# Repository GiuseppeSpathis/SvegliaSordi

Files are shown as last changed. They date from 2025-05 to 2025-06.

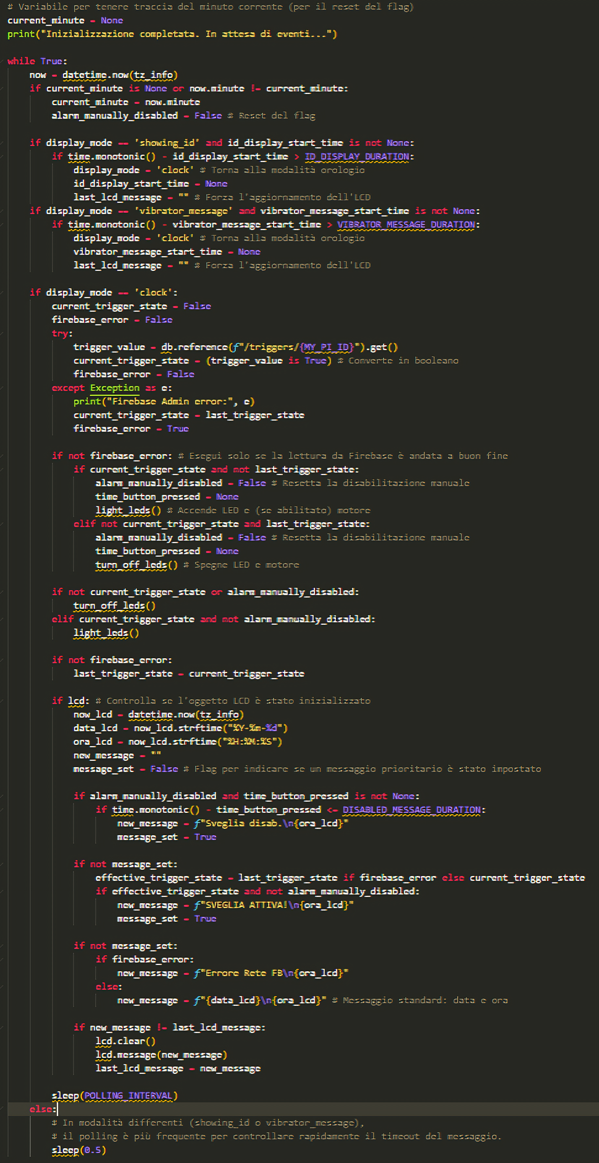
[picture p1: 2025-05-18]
utilsRelazione/codeBlocks4.PNG

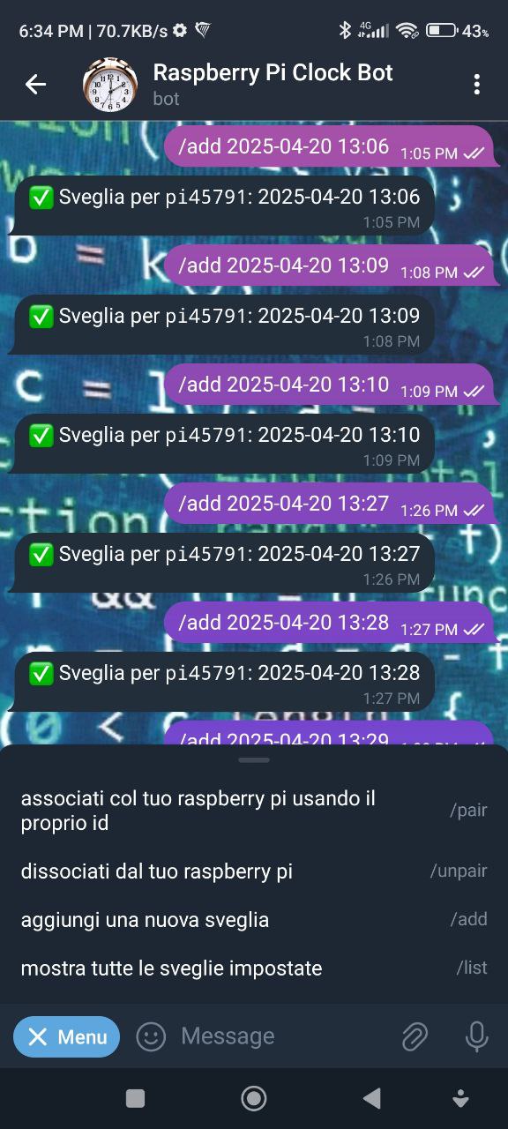
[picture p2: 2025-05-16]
utilsRelazione/botTelegram.jpg

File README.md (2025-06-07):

# SvegliaSordi
This project, titled "Sveglia per Sordi" (Alarm Clock for the Deaf), aims to create an alarm clock specifically designed for individuals who are deaf, hard of hearing, or have other auditory difficulties. Instead of traditional acoustic stimuli, the device uses visual (LED lights) and tactile (a vibrating motor, e.g., placed under a pillow) signals to wake the user.

The alarm clock can be controlled remotely via a Telegram bot ("Raspberry Pi Clock Bot"), allowing users to set, modify, or delete alarms. The system supports multiple users, with each alarm associated with a specific Raspberry Pi, making it scalable. Alarm data is stored in a Firebase Realtime Database for synchronization across devices. The Telegram bot management runs on a separate server, while a Python script on a Raspberry Pi Zero continuously monitors the database and activates the alarm signals (LEDs and vibration) at the scheduled time. The project also includes a custom 3D-printed case to house all the components, creating a compact and user-friendly device.

Key innovative aspects include the combined use of visual and tactile stimuli, remote alarm management via Telegram and a Firebase data synchronization for multi-device access

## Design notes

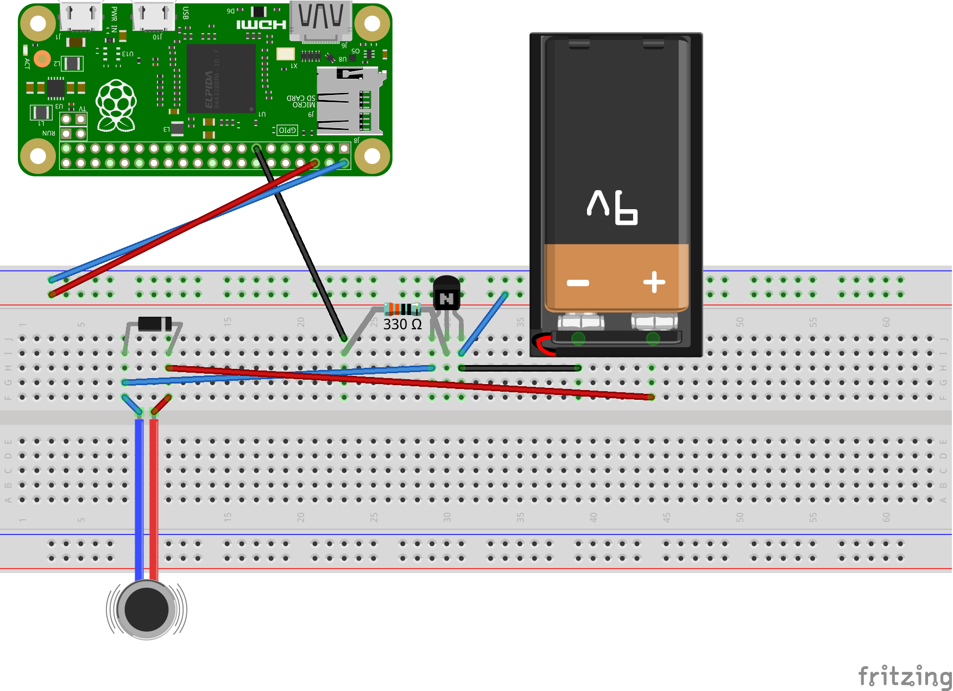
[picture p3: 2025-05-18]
utilsRelazione/vibratorMotor_fritzing.png

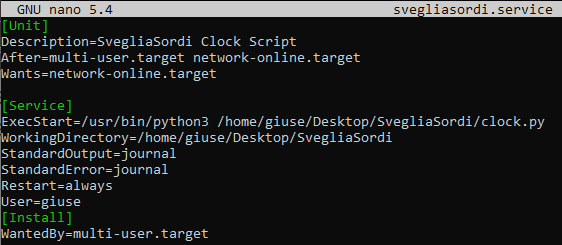
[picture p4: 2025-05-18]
utilsRelazione/ServiceBlock.PNG

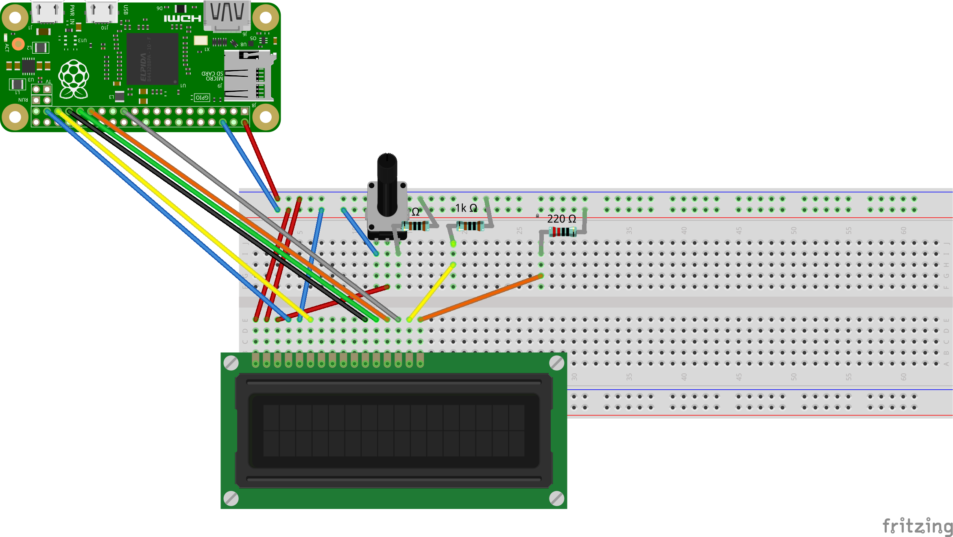
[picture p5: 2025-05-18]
utilsRelazione/schemaLcd_fritzing.png

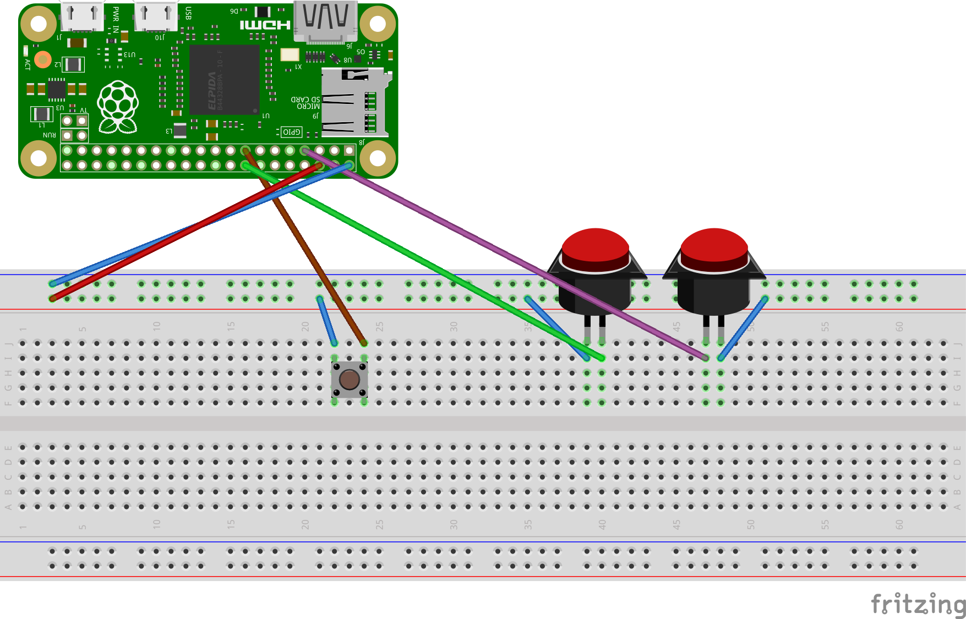
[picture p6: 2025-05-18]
utilsRelazione/buttons_fritzing.png

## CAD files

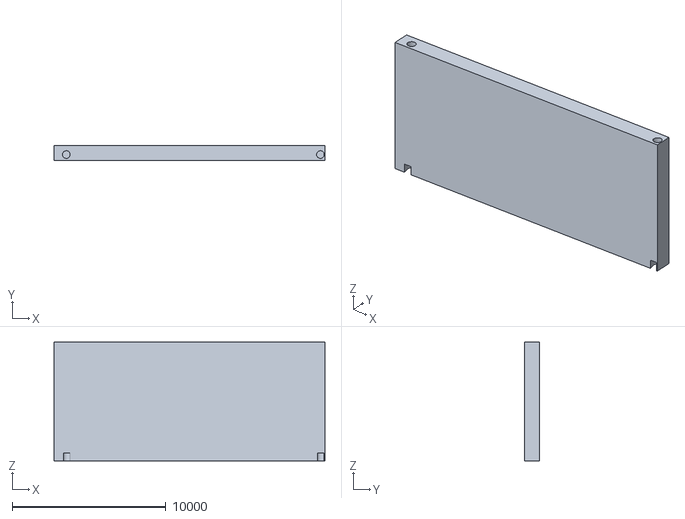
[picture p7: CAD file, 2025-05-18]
blueprint3d/parete_only_no_holes.stl
17600.0 x 1000.0 x 7700.0

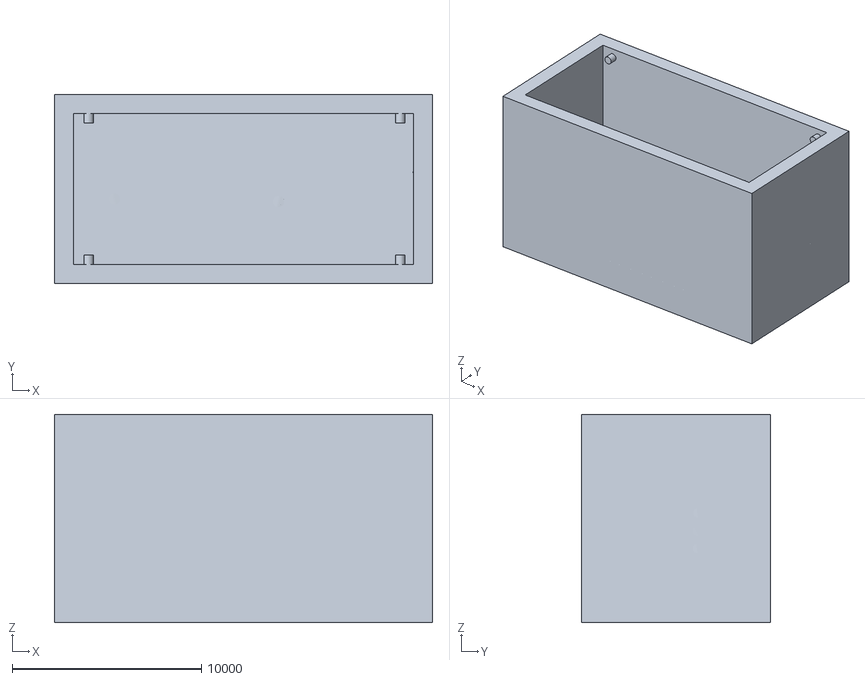
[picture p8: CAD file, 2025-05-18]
blueprint3d/case_only_no.stl
20000.0 x 10000.0 x 11016.2

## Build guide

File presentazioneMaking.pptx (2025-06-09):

## Università di Bologna Dipartimento di informatica LABORATORIO DI MAKING

Progetto “Sveglia per Sordi”
Di Giuseppe Spathis

Prof. Federico Montori
Prof. Renzo Davoli
______________________________________________________________________________________________
Anno Accademico: 2024-2025

## OBIETTIVO

L'obiettivo del mio progetto è creare una sveglia innovativa pensata per chi ha difficoltà uditive, ma anche per chi, come me, non sente le sveglie tradizionali (ad esempio, a causa dell'uso di tappi per le orecchie).
Questa sveglia non usa suoni, ma si basa su segnali visivi e tattili. Al momento del risveglio, attiverà:
- LED luminosi
- Un motorino vibrante, ideale da mettere sotto il cuscino.
Questa soluzione nasce da un'esigenza personale, ma mira a offrire un risveglio efficace, affidabile e personalizzabile a tutti coloro che cercano un'alternativa valida alle sveglie acustiche.

## ANALISI DELLA LETTERATURA

Le sveglie esistenti per persone sorde spesso usano la vibrazione o, in alcuni casi, leggere scosse elettriche. È stata esclusa l’idea di scosse, ritenendole troppo invasive per l'uso quotidiano.
Per questo, è stato scelto di focalizzarsi sulla vibrazione, ma è stata integrata con un sistema di segnalazione visiva a LED.

## FUNZIONALITÀ

- Controllo Remoto: gestione via Telegram Bot.
- Gestione Sveglie: imposta, modifica o cancella sveglie facilmente.
- Multiutenza: supporto per più utenti e scalabilità
- Database Realtime: dati sveglie salvati e sincronizzati con Firebase.
- Architettura Distribuita: bot Telegram su server dedicato.
- Script Python su Raspberry Pi Zero per attivazione sveglie.
- Design Ottimizzato: case 3D personalizzato per un dispositivo compatto e pronto all'uso.

## BOT TELEGRAM

Immagine che contiene testo, schermata, software, design Il contenuto generato dall'IA potrebbe non essere corretto.

- Bot Telegram creato con BotFather.
- Funzionalità Chiave: aggiunta nuove sveglie, modifica sveglie esistenti e sistema di pairing

## DATABASE FIREBASE

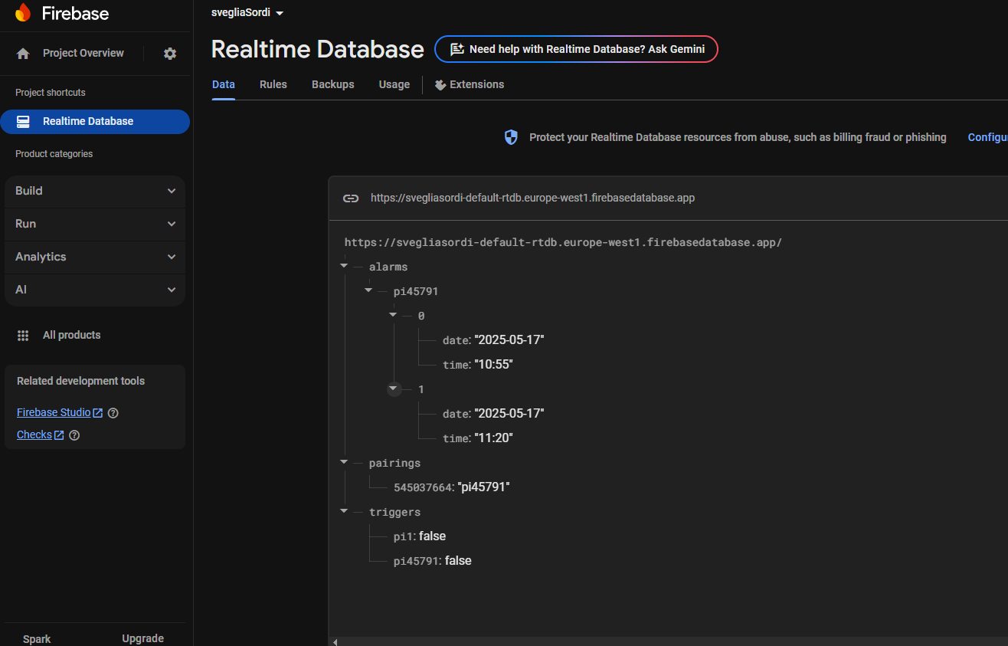
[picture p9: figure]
Immagine che contiene testo, schermata, software, Software multimediale Il contenuto generato dall'IA potrebbe non essere corretto.

## DESIGN 3D

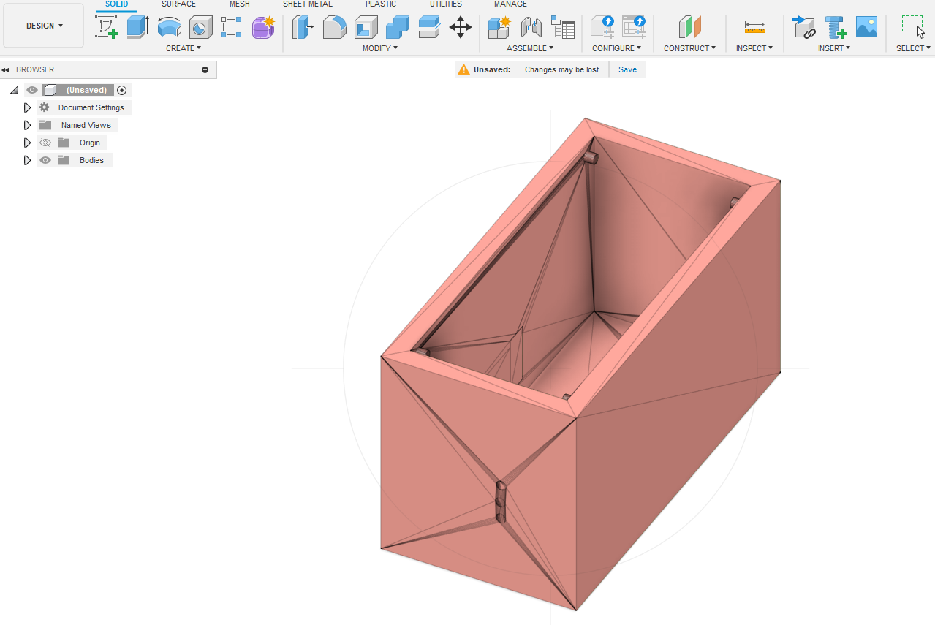
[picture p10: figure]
Immagine che contiene schermata, testo, design, scatola Il contenuto generato dall'IA potrebbe non essere corretto.

## STAMPA 3D

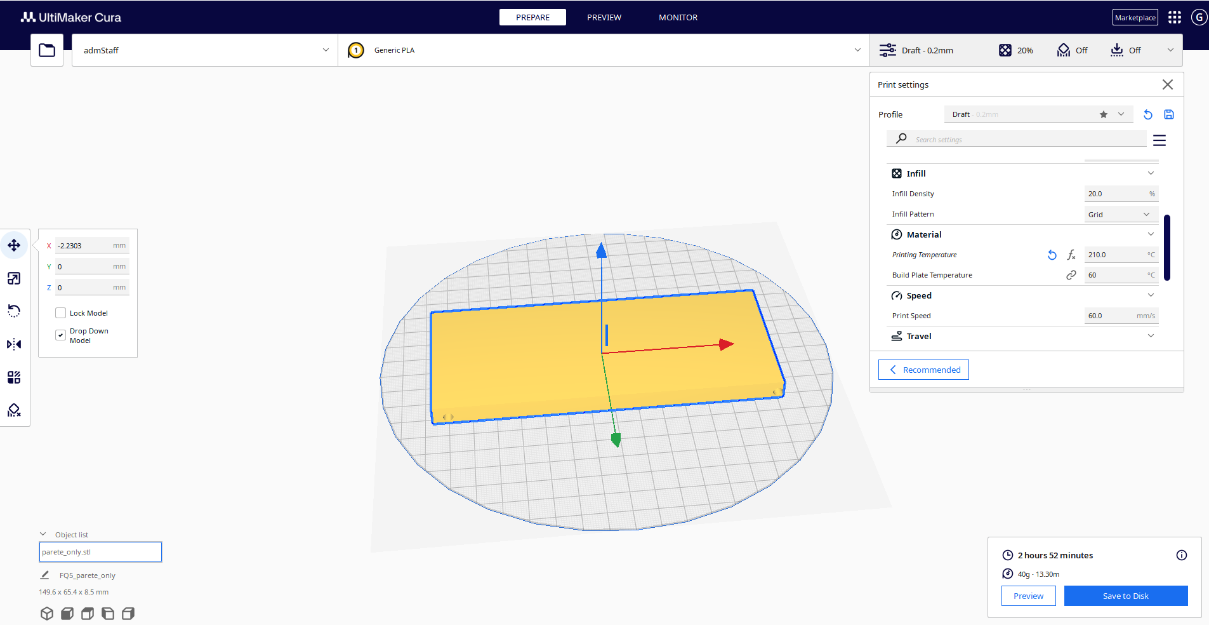
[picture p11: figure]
Immagine che contiene testo, schermata, diagramma, software Il contenuto generato dall'IA potrebbe non essere corretto.

## SCHERMO LCD

Immagine che contiene circuito, schermata, linea, Ingegneria elettronica Il contenuto generato dall'IA potrebbe non essere corretto.

## LED

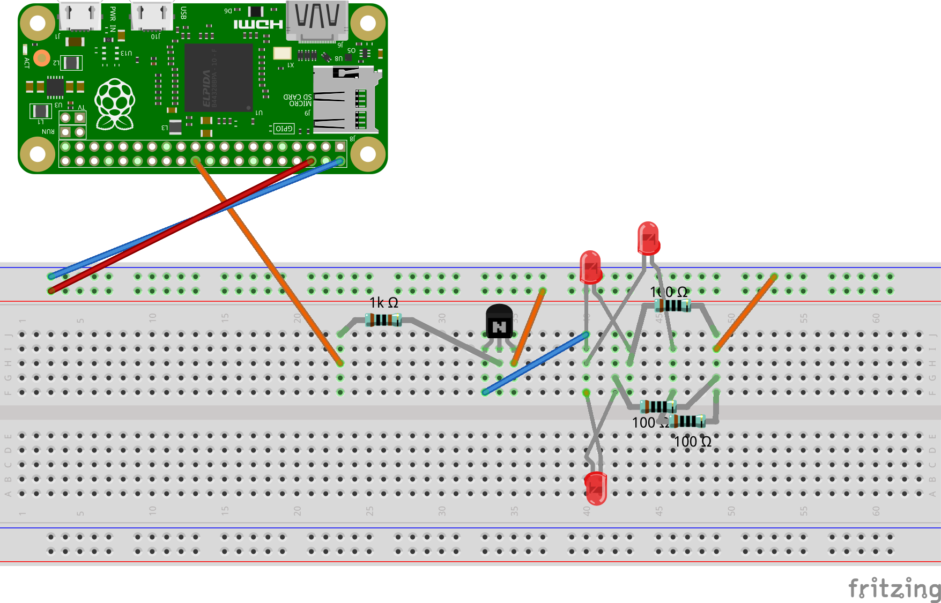
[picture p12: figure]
Immagine che contiene Ingegneria elettronica, circuito, Componente elettrico, Componente di circuito Il contenuto generato dall'IA potrebbe non essere corretto.

## VIBRATOR MOTOR

Immagine che contiene testo, circuito, elettronica, Ingegneria elettronica Il contenuto generato dall'IA potrebbe non essere corretto.

## PULSANTI

Immagine che contiene circuito, Ingegneria elettronica, linea, testo Il contenuto generato dall'IA potrebbe non essere corretto.

## SFIDE INCONTRATE

- Durante lo sviluppo del progetto, sono emerse alcune sfide tecniche che hanno richiesto l'adozione di soluzioni alternative.
- Si è riscontrato un problema con il sensore di movimento, che creava troppi falsi positivi.
- Si è incontrata difficoltà nella stampa del case in 3D, poiché inizialmente si è tentato di stampare con una stampante che presentava difetti nel piatto.

## LAVORI FUTURI

- Ottimizzazione del Case 3D: si può migliorare il design integrando una chiusura magnetica per la parete rimovibile.
- Potenziamento delle Notifiche Fisiche: si può aumentare l'efficacia delle segnalazioni tattili e visive con un motorino vibrante più potente e LED ad alta luminosità o in numero maggiore.
- Maggiore Accessibilità: si potrebbe integrare un buzzer per fornire notifiche sonore personalizzabili, rendendo la sveglia fruibile anche per utenti ipoudenti.
- Funzionalità Software Avanzate: si possono introdurre sveglie ricorrenti dal bot Telegram o l'integrazione con servizi smart home.
- Affidabilità Migliorata: si può implementare un backup locale delle sveglie sul Raspberry Pi per garantire il funzionamento anche senza connessione internet.

## CONCLUSIONI

- Il progetto ha dimostrato la fattibilità di una sveglia alternativa basata su stimoli visivi e tattili.
- È stato sviluppato un prototipo completo che integra hardware, controllo remoto via Telegram Bot e gestione dati su Firebase Cloud, il tutto in un case 3D personalizzato.
- L'iterazione progettuale ha permesso di affrontare e risolvere sfide tecniche, consolidando l'apprendimento pratico.
- Il prototipo attuale raggiunge l'obiettivo primario di fornire un sistema di sveglia efficace e personalizzabile.
- Esistono margini di miglioramento per le notifiche fisiche e la resilienza alla disconnessione da Internet.

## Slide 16

Grazie per l’attenzione

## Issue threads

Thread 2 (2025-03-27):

Todo allarme sveglia

GiuseppeSpathis, 2025-03-27:
Appena si arriva alla data di una sveglia (problema partono pure le sveglie degli altri utenti, chiedere al prof) nel display LCD deve apparire la scritta sveglia in corso /n spegnere cliccando col bottone, nel mentre una o più lampadine (vedere se esistono lampadine più potenti) devono accendersi e spegnersi in continuazione fin quando non clicchi il bottone

Closed 2025-05-19.

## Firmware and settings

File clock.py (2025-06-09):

# clock.py
# Legge trigger da Firebase, controlla LED/LCD, bottone disabilitazione,
# bottone mostra ID, gestisce il vibrator motor, e resetta il flag di disabilitazione all'inizio di ogni nuovo minuto.

import RPi.GPIO as GPIO
from Adafruit_CharLCD import Adafruit_CharLCD
from gpiozero import Button
import time
from time import sleep
import signal
import sys
import pytz
from datetime import datetime
import random   # Per generare ID random
import os       # Per controllare esistenza file
import firebase_admin
from firebase_admin import credentials, db

# --- Configurazione Utente ---
# Pin GPIO (BCM numbering)
LCD_RS = 26
LCD_E  = 19
LCD_D4 = 13
LCD_D5 = 6
LCD_D6 = 5
LCD_D7 = 11
LED_PIN = 25
MOTOR_PIN = 27                     # Pin per il vibrator motor
DISABLE_BUTTON_PIN = 23            # Bottone per disabilitare sveglia attiva
ID_DISPLAY_BUTTON_PIN = 4          # Bottone Giallo per mostrare ID (GPIO 4)
VIBRATOR_TOGGLE_BUTTON_PIN = 22    # Bottone per abilitare/disabilitare il vibrator motor

# Firebase
FIREBASE_DB_URL = "https://svegliasordi-default-rtdb.europe-west1.firebasedatabase.app"

# Altro
TIMEZONE = "Europe/Rome"
POLLING_INTERVAL = 2              # Secondi tra i controlli per l'LCD
DISABLED_MESSAGE_DURATION = 8     # Secondi per cui mostrare "Sveglia disab."
ID_DISPLAY_DURATION = 12          # Secondi per cui mostrare l'ID Pi
VIBRATOR_MESSAGE_DURATION = 2     # Durata in secondi del messaggio sullo schermo per il vibrator motor
PI_ID_FILENAME = "pi_id.txt"      # Nome del file per salvare l'ID
# --- Fine Configurazione Utente ---


# --- Variabili Globali di Stato ---
alarm_manually_disabled = False      # Flag per disabilitazione manuale
time_button_pressed = None           # Timestamp della pressione del bottone disabilitazione
last_lcd_message = ""
last_trigger_state = False           # Stato precedente del trigger ricevuto da Firebase
display_mode = 'clock'               # 'clock', 'showing_id' o 'vibrator_message'
id_display_start_time = None         # Timestamp per timeout display ID
vibrator_motor_enabled = True        # Vibrator motor abilitato di default
vibrator_message_start_time = None   # Timestamp per il timeout del messaggio vibrator
startup_time = time.monotonic()      # Tempo di avvio del programma (per eventuale gestione errori)

# --- Funzione per Leggere/Generare ID Pi ---
def get_or_generate_pi_id(filename: str):
    """
    Legge l'ID Pi dal file specificato. Se il file non esiste o è invalido,
    genera un nuovo ID nel formato 'piXXXXX', lo salva nel file e lo restituisce.
    """
    script_dir = os.path.dirname(os.path.realpath(__file__))
    filepath = os.path.join(script_dir, filename)

    if os.path.exists(filepath):
        with open(filepath, "r") as f:
            pi_id = f.read().strip()
        if pi_id.startswith("pi") and len(pi_id) == 7 and pi_id[2:].isdigit():
            return pi_id, script_dir
        else:
            os.remove(filepath)

    random_part = random.randint(0, 99999)
    new_id = f"pi{random_part:05d}"
    with open(filepath, "w") as f:
        f.write(new_id)
    return new_id, script_dir


# --- Ottieni l'ID del Pi all'avvio ---
MY_PI_ID, script_dir = get_or_generate_pi_id(PI_ID_FILENAME)

cred = credentials.Certificate(os.path.join(script_dir, "firebaseKey.json"))
firebase_admin.initialize_app(cred, {
    "databaseURL": FIREBASE_DB_URL
})

# --- Setup Hardware ---
lcd = None
disable_button = None
id_display_button = None
vibrator_toggle_button = None

tz_info = pytz.timezone(TIMEZONE)
GPIO.setmode(GPIO.BCM)

# Configura LED e vibrator motor
GPIO.setup(LED_PIN, GPIO.OUT, initial=GPIO.LOW)
GPIO.setup(MOTOR_PIN, GPIO.OUT, initial=GPIO.LOW)

# Configura bottoni con gpiozero
disable_button = Button(DISABLE_BUTTON_PIN, pull_up=True)
id_display_button = Button(ID_DISPLAY_BUTTON_PIN, pull_up=True)
vibrator_toggle_button = Button(VIBRATOR_TOGGLE_BUTTON_PIN, pull_up=True)

# Inizializza LCD
lcd = Adafruit_CharLCD(
    rs=LCD_RS, en=LCD_E, d4=LCD_D4, d5=LCD_D5, d6=LCD_D6, d7=LCD_D7,
    cols=16, lines=2
)
lcd.clear()
lcd.enable_display(True)
lcd.home()


# --- Funzioni per gestire LED e Vibrator Motor ---
def light_leds():
    """Accende i LED e, se abilitato, anche il vibrator motor."""
    GPIO.output(LED_PIN, GPIO.HIGH)
    if vibrator_motor_enabled:
        GPIO.output(MOTOR_PIN, GPIO.HIGH)


def turn_off_leds():
    """Spegne i LED e il vibrator motor."""
    GPIO.output(LED_PIN, GPIO.LOW)
    GPIO.output(MOTOR_PIN, GPIO.LOW)


# --- Callback per il listener Firebase ---
def on_trigger_change(event):
    """
    Eseguito non appena cambia il valore in /triggers/MY_PI_ID.
    event.data == True  → accendi sveglia
    event.data == False → spegni sveglia
    """
    global alarm_manually_disabled, last_trigger_state

    valore = event.data  # Può essere True, False o None
    if valore is True and not last_trigger_state:
        # Nuovo trigger a True → accendi sveglia
        alarm_manually_disabled = False
        light_leds()
        last_trigger_state = True

    elif valore is False and last_trigger_state:
        # Trigger tornato a False → spegni sveglia
        alarm_manually_disabled = False
        turn_off_leds()
        last_trigger_state = False

    # Se valore è None o uguale allo stato precedente, non fare nulla


# --- Callback per il bottone di disabilitazione ---
def disable_button_pressed_callback():
    """
    Callback per il bottone DISABLE_BUTTON_PIN.
    Se c'è una sveglia in corso, la disabilita e azzera anche il trigger in Firebase.
    """
    global alarm_manually_disabled, time_button_pressed

    if last_trigger_state and not alarm_manually_disabled:
        alarm_manually_disabled = True
        time_button_pressed = time.monotonic()
        turn_off_leds()

        try:
            db.reference(f'/triggers/{MY_PI_ID}').set(False)
            print("DEBUG: Trigger resettato a False su Firebase (button disable).")
        except Exception as e:
            print(f"Errore nel resettare il trigger su Firebase: {e}")


# --- Callback per il bottone di visualizzazione ID ---
def id_display_button_callback():
    """
    Callback per il bottone ID_DISPLAY_BUTTON_PIN.
    Mostra l'ID del dispositivo sul display per un breve periodo.
    """
    global display_mode, id_display_start_time, last_lcd_message

    if display_mode == 'showing_id':
        # Se già in mostra ID, ripristina semplicemente il timer
        id_display_start_time = time.monotonic()
        return

    display_mode = 'showing_id'
    id_display_start_time = time.monotonic()
    if lcd:
        lcd.clear()
        if len(MY_PI_ID) > 16:
            lcd.message(f"ID:{MY_PI_ID[:16]}\n{MY_PI_ID[16:]}")
        else:
            lcd.message(f"ID Dispositivo:\n{MY_PI_ID.center(16)}")


# --- Callback per il bottone di toggle vibrator motor ---
def vibrator_motor_toggle_callback():
    """
    Callback per il bottone VIBRATOR_TOGGLE_BUTTON_PIN.
    Abilita/disabilita il vibrator motor e mostra un messaggio temporaneo.
    """
    global vibrator_motor_enabled, display_mode, vibrator_message_start_time, last_lcd_message

    vibrator_motor_enabled = not vibrator_motor_enabled
    status_msg = "vibrator motor \nabilitato" if vibrator_motor_enabled else "vibrator motor \ndisabilitato"
    display_mode = 'vibrator_message'
    vibrator_message_start_time = time.monotonic()

    if lcd:
        lcd.clear()
        lcd.message(status_msg)


# Associa le callback ai bottoni
if disable_button:
    disable_button.when_pressed = disable_button_pressed_callback

if id_display_button:
    id_display_button.when_pressed = id_display_button_callback

if vibrator_toggle_button:
    vibrator_toggle_button.when_pressed = vibrator_motor_toggle_callback


def cleanup_resources(signum=None, frame=None):
    """Pulisce GPIO e LCD prima di uscire."""
    global lcd
    if lcd:
        lcd.clear()
        lcd.enable_display(False)

    if 'GPIO' in sys.modules and GPIO.getmode() is not None:
        GPIO.output(LED_PIN, GPIO.LOW)
        GPIO.output(MOTOR_PIN, GPIO.LOW)
        GPIO.cleanup()

    sys.exit(0)


signal.signal(signal.SIGINT, cleanup_resources)
signal.signal(signal.SIGTERM, cleanup_resources)


# --- Imposta il listener Firebase per i trigger ---
trigger_ref = db.reference(f"/triggers/{MY_PI_ID}")
trigger_ref.listen(on_trigger_change)


# --- Loop Principale ---
current_minute = None
print("Inizializzazione completata. In attesa di eventi...")

while True:
    # Reset del flag alarm_manually_disabled all'inizio di ogni nuovo minuto
    now = datetime.now(tz_info)
    if current_minute is None or now.minute != current_minute:
        current_minute = now.minute
        alarm_manually_disabled = False

    # Gestione timeout dei messaggi temporanei (ID e vibrator)
    if display_mode == 'showing_id' and id_display_start_time is not None:
        if time.monotonic() - id_display_start_time > ID_DISPLAY_DURATION:
            display_mode = 'clock'
            id_display_start_time = None
            last_lcd_message = ""

    if display_mode == 'vibrator_message' and vibrator_message_start_time is not None:
        if time.monotonic() - vibrator_message_start_time > VIBRATOR_MESSAGE_DURATION:
            display_mode = 'clock'
            vibrator_message_start_time = None
            last_lcd_message = ""

    if display_mode == 'clock':
        # 3. Aggiornamento orologio su LCD
        if lcd:
            now_lcd = datetime.now(tz_info)
            data_lcd = now_lcd.strftime("%Y-%m-%d")
            ora_lcd = now_lcd.strftime("%H:%M:%S")
            new_message = ""
            message_set = False

            # Se la sveglia è disabilitata manualmente
            if alarm_manually_disabled and time_button_pressed is not None:
                if time.monotonic() - time_button_pressed <= DISABLED_MESSAGE_DURATION:
                    new_message = f"Sveglia disab.\n{ora_lcd}"
                    message_set = True

            if not message_set:
                # Se il trigger è attivo e non è disabilitato manualmente
                if last_trigger_state and not alarm_manually_disabled:
                    new_message = f"SVEGLIA ATTIVA!\n{ora_lcd}"
                    message_set = True

            if not message_set:
                new_message = f"{data_lcd}\n{ora_lcd}"

            if new_message != last_lcd_message:
                lcd.clear()
                lcd.message(new_message)
                last_lcd_message = new_message

        sleep(POLLING_INTERVAL)

    else:
        # In modalità 'showing_id' o 'vibrator_message', controlla più spesso il timeout
        sleep(0.5)

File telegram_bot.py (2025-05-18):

# telegram_bot.py
# Gestisce il bot Telegram, salva/legge allarmi su Firebase,
# controlla l'ora e invia trigger al Pi tramite Firebase.

import json
import logging
from datetime import datetime, timedelta
import pytz
import time
import threading
import signal # Per gestire SIGTERM/SIGINT nel thread
from telegram import Update
from telegram.ext import Application, CommandHandler, CallbackContext
import firebase_admin
from firebase_admin import credentials, db


# --- Configurazione Utente ---
BOT_TOKEN = "7824989957:AAETWh9iqhzKDChpgDZ1GsMGijHUusOxziI" 
PATH_TO_FIREBASE_KEY = "firebaseKey.json" 
FIREBASE_DB_URL = "https://svegliasordi-default-rtdb.europe-west1.firebasedatabase.app" 
PI_ID = "pi45791" # Identificativo del Raspberry Pi da triggerare
TIMEZONE = "Europe/Rome"
# --- Fine Configurazione Utente ---

# Setup Logging
logging.basicConfig(format="%(asctime)s - %(name)s - %(levelname)s - %(message)s", level=logging.INFO)
logging.getLogger("httpx").setLevel(logging.WARNING)
logger = logging.getLogger(__name__)

logger = logging.getLogger(__name__)
keep_running = True
try:
    tz_info = pytz.timezone(TIMEZONE)
    cred = credentials.Certificate(PATH_TO_FIREBASE_KEY)
    firebase_admin.initialize_app(cred, {'databaseURL': FIREBASE_DB_URL})
    logger.info("Firebase Admin SDK inizializzato correttamente.")
except Exception as e:
     logger.error(f"Errore inizializzazione Firebase: {e}", exc_info=True); exit()

# --- Funzioni Database Firebase ---

def get_pi_id_for_user(user_id: str) -> str | None:
    """Recupera il pi_id associato a un utente da /pairings/{user_id}."""
    try:
        ref = db.reference(f'/pairings/{user_id}')
        pi_id = ref.get()
        return str(pi_id) if pi_id else None
    except Exception as e:
        logger.error(f"Errore leggendo pairing per {user_id}: {e}")
        return None

def save_pairing(user_id: str, pi_id: str):
    """Salva l'associazione utente-Pi."""
    try:
        ref = db.reference(f'/pairings/{user_id}')
        ref.set(pi_id)
    except Exception as e:
        logger.error(f"Errore salvando pairing per {user_id} -> {pi_id}: {e}")

def delete_pairing(user_id: str):
     """Rimuove l'associazione utente-Pi."""
     try:
         ref = db.reference(f'/pairings/{user_id}')
         ref.delete()
     except Exception as e:
         logger.error(f"Errore cancellando pairing per {user_id}: {e}")


def load_alarms_for_pi(pi_id: str) -> list:
    """Carica gli allarmi per un Pi specifico da /alarms/{pi_id}."""
    if not pi_id: return []
    try:
        ref = db.reference(f'/alarms/{pi_id}')
        alarms = ref.get()
        return alarms if isinstance(alarms, list) else []
    except Exception as e:
        logger.error(f"Errore leggendo allarmi per {pi_id}: {e}")
        return []

def save_alarms_for_pi(pi_id: str, alarms: list):
    """Salva la lista allarmi per un Pi specifico su /alarms/{pi_id}."""
    if not pi_id: return
    try:
        ref = db.reference(f'/alarms/{pi_id}')
        ref.set(alarms)
    except Exception as e:
        logger.error(f"Errore salvando allarmi per {pi_id}: {e}")

def load_all_pi_alarms() -> dict:
    """Carica TUTTI gli allarmi di TUTTI i Pi da /alarms."""
    try:
        ref = db.reference('/alarms')
        all_alarms_dict = ref.get()
        # Filtra eventuali valori non-dizionario o chiavi non-stringa (poco probabile ma sicuro)
        return {str(k): v for k, v in all_alarms_dict.items() if isinstance(k, str) and isinstance(v, list)} if isinstance(all_alarms_dict, dict) else {}
    except Exception as e:
        logger.error(f"Errore leggendo tutti gli allarmi dei Pi: {e}")
        return {}

# --- Decorator per Controllo Pairing ---
from functools import wraps

def require_pairing(func):
    """Decorator per verificare se l'utente è associato a un Pi."""
    @wraps(func)
    async def wrapper(update: Update, context: CallbackContext, *args, **kwargs):
        user_id = str(update.effective_user.id)
        pi_id = get_pi_id_for_user(user_id)
        if not pi_id:
            await update.message.reply_text(
                "❗️ Non sei associato a nessun dispositivo.\n"
                "Premi il bottone giallo sul tuo Raspberry Pi per vedere il suo ID, "
                "poi usa il comando:\n`/pair ID_DEL_TUO_PI`"
            )
            return None # Blocca l'esecuzione del comando
        # Passa il pi_id al contesto per usarlo nel comando
        context.user_data['pi_id'] = pi_id
        return await func(update, context, *args, **kwargs)
    return wrapper

# --- Funzioni Handler Comandi Bot  ---

async def start(update: Update, context: CallbackContext):
    user_id = str(update.effective_user.id)
    pi_id = get_pi_id_for_user(user_id)
    welcome_message = (
        f"👋 Ciao, {update.effective_user.first_name}!\n"
    )
    if pi_id:
         welcome_message += f"Sei associato al dispositivo: `{pi_id}`\n\n"
    else:
         welcome_message += "Non sei associato a nessun dispositivo.\nUsa `/pair ID_PI` per iniziare.\n\n"

    welcome_message += (
        "✅ Comandi:\n"
        "🔹 `/pair ID_PI` - Associa questo bot al tuo rasperry pi usando il pi\\_id visibile cliccando sul bottone giallo del rasperry\n"
        "🔹 `/unpair` - Dissocia questo bot dal tuo rasperry\n"
        "🔹 `/add YYYY-MM-DD HH:MM` - Aggiungi sveglia (richiede pairing)\n"
        "🔹 `/list` - Mostra sveglie (richiede pairing)\n"
        "🔹 `/delete ID` - Elimina sveglia (richiede pairing)\n\n"
        "💾 Sveglie su Firebase! 🔥"
    )
    await update.message.reply_text(welcome_message, parse_mode='Markdown')


async def pair_command(update: Update, context: CallbackContext):
    """Associa l'utente Telegram a un Pi ID."""
    user_id = str(update.effective_user.id)
    if not context.args or len(context.args) != 1:
        await update.message.reply_text("❌ Formato non valido. Usa: `/pair ID_DEL_TUO_PI`\n(Trovi l'ID premendo il bottone giallo sul Pi).")
        return
    pi_id_to_pair = context.args[0].strip()
    if not pi_id_to_pair:
         await update.message.reply_text("❌ ID non valido.")
         return

    save_pairing(user_id, pi_id_to_pair)
    logger.info(f"Utente {user_id} associato a Pi {pi_id_to_pair}")
    await update.message.reply_text(f"✅ Associato con successo al dispositivo `{pi_id_to_pair}`!", parse_mode='Markdown')

async def unpair_command(update: Update, context: CallbackContext):
     """Dissocia l'utente Telegram dal Pi."""
     user_id = str(update.effective_user.id)
     pi_id = get_pi_id_for_user(user_id)
     if not pi_id:
         await update.message.reply_text("ℹ️ Non sei attualmente associato a nessun dispositivo.")
         return

     delete_pairing(user_id)
     logger.info(f"Utente {user_id} dissociato dal Pi {pi_id}")
     await update.message.reply_text(f"✅ Associazione con il dispositivo `{pi_id}` rimossa.", parse_mode='Markdown')
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

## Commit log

2025-04-08 messo sistema di codice per multiutenza
2025-05-05 aggiunti schemi e sistemato codice
    [buttons.fzz, leds.fzz, scheletro.fzz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]
2025-05-07 aggiunti file per la relazione
    [buttons.fzz, case_only.stl, leds.fzz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]
2025-05-16 sistemate varie cose per la relazione
    [schemaLcd.fzz]
2025-05-18 aggiunti nei file per la relazione e sistemato clock.py
    [case_only.stl, case_only_no.stl, leds.fzz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]
2025-05-18 pulito il codice
2025-06-07 finita la presentazione in pptx
2025-06-09 aggiornata la presentazione
